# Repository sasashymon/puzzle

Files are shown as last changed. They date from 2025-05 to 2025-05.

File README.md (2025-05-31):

Práce se zaměřuje na praktické ověření principů digitálně distribuované výroby prostřednictvím návrhu a dokumentace jednoduché stoličky Puzzle. Cílem bylo vytvořit produkt, který odráží možnosti lokální digitální výroby a zároveň snižuje bariéry vstupu pro běžné uživatele díky srozumitelné dokumentaci, otevřeným výrobním datům a snadné montáži. Návrh stoličky Puzzle slouží jako případová studie propojující tech nologický potenciál s uživatelsky orientovaným designem. Práce ukazuje, že distribuovaná výroba může být díky promyšlenému návrhu a přístupnosti relevantní i pro neodbornou veřejnost.

Seznam souborů:

proUzivatele.pdf – tento průvodce výrobou 
proVyrobce.pdf – poznámky pro výrobce 
sedak[18/21].dxf, strana[18/21].dxf – kontury dílů 
puzzle[18/21].stp – 3D model 
vykres[18/21].pdf – technický výkres dílů 
puzzleParam.f3d – parametrický model pro úpravu v Autodesk Fusion

Soubory jsou připraveny pro materiál o tloušťce 18 a 21 mm. V případě použití jiné tloušťky materiálu je k dispozici parametrický model ve formátu F3D (pro Autodesk Fusion), který umožňuje snadnou úpravu.

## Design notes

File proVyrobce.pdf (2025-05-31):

## Přehled výrobních podkladů

{ proVyrobce.pdf – tyto poznámky pro výrobcC

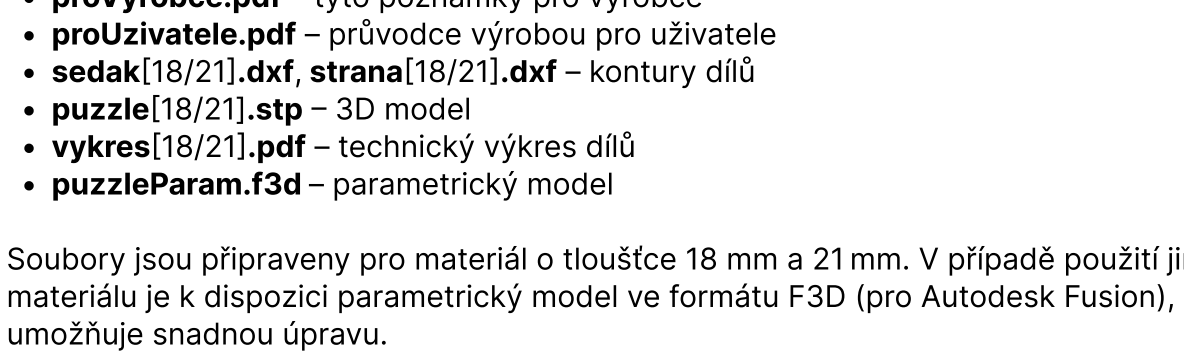
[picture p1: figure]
{ puzzle[18/21].stp – 3D mode6; { puzzleParam.f3d – parametrický model; umožňuje snadnou úpravu.

{ proUzivatele.pdf – průvodce výrobou pro uživatelC { sedak[18/21].dxf, strana[18/21].dxf – kontury díl

{ vykres[18/21].pdf – technický výkres díl

Soubory jsou připraveny pro materiál o tloušťce 18 mm a 21 mm. V případě použití jiné tloušťky materiálu je k dispozici parametrický model ve formátu F3D (pro Autodesk Fusion), který

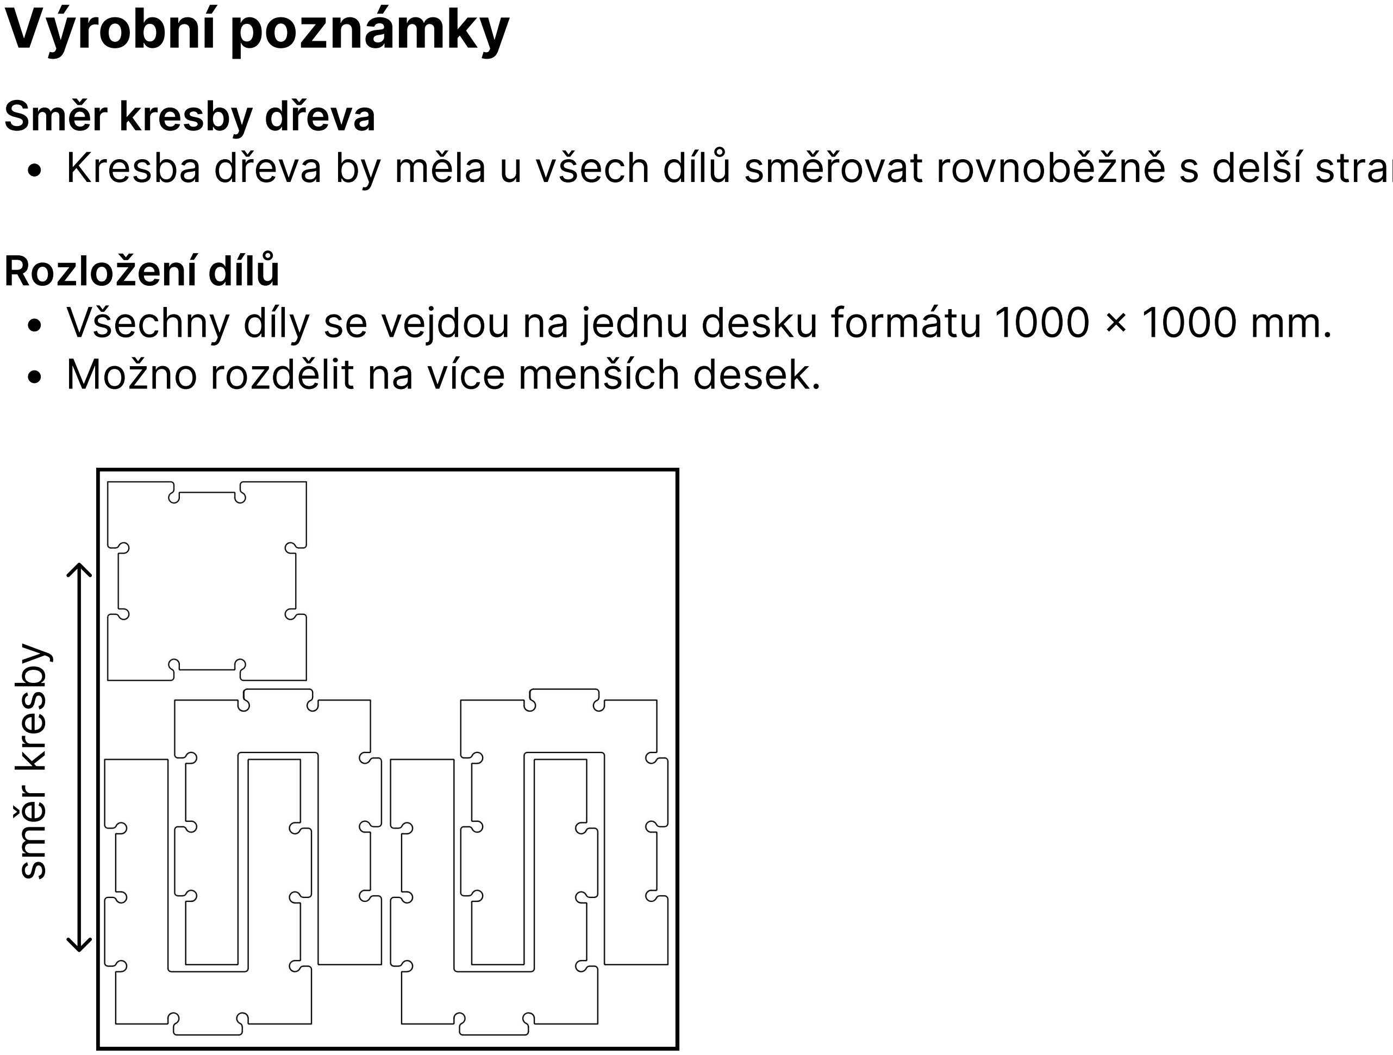
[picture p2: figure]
Výrobní poznámky; Směr kresby dřev´; Rozložení díl; ® Možno rozdělit na více menších desek.; směr kresby

® Kresba dřeva by měla u všech dílů směřovat rovnoběžně s delší stranou.

® Všechny díly se vejdou na jednu desku formátu 1000 × 1000 mm¦

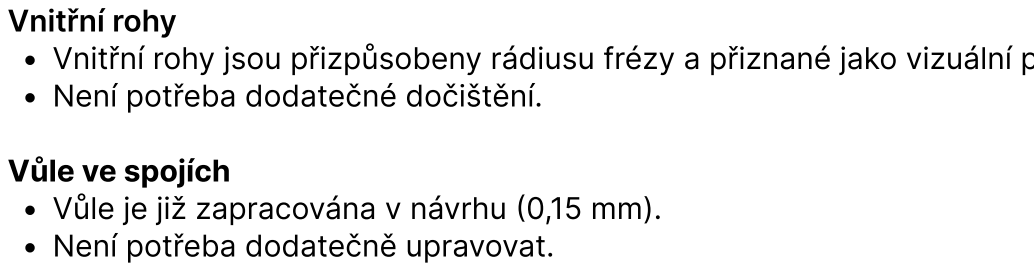
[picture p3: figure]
Vnitřní rohB; ® Není potřeba dodatečné dočištění.; Vůle ve spojíc; ® Není potřeba dodatečně upravovat.

® Vnitřní rohy jsou přizpůsobeny rádiusu frézy a přiznané jako vizuální prve

® Vůle je již zapracována v návrhu (0,15 mm)¦

1/1

# Poznámky pro výrobce stolička Puzzle

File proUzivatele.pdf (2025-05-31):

# Průvodce výrobou – stolička Puzzle

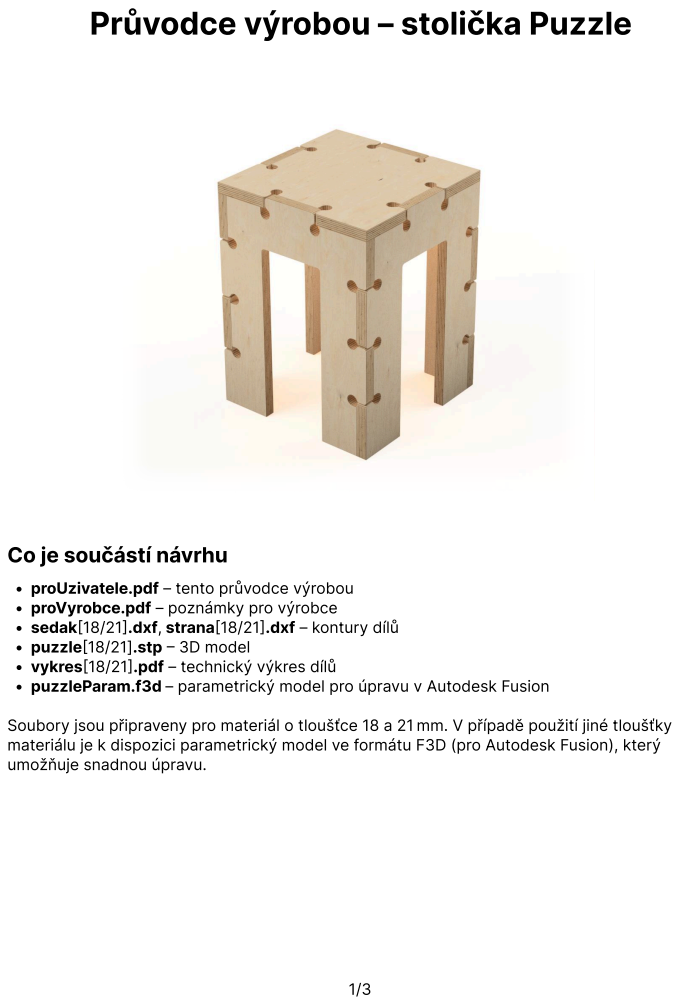
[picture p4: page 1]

Co je součástí návrhu

x proUzivatele.pdf – tento průvodce výrobo
x proVyrobce.pdf – poznámky pro výrobcW
x sedak[18/21].dxf, strana[18/21].dxf – kontury díl"
x puzzle[18/21].stp – 3D mode)
x vykres[18/21].pdf – technický výkres díl"
x puzzleParam.f3d – parametrický model pro úpravu v Autodesk Fusion

Soubory jsou připraveny pro materiál o tloušťce 18 a 21 mm. V případě použití jiné tloušťky
materiálu je k dispozici parametrický model ve formátu F3D (pro Autodesk Fusion), který
umožňuje snadnou úpravu.

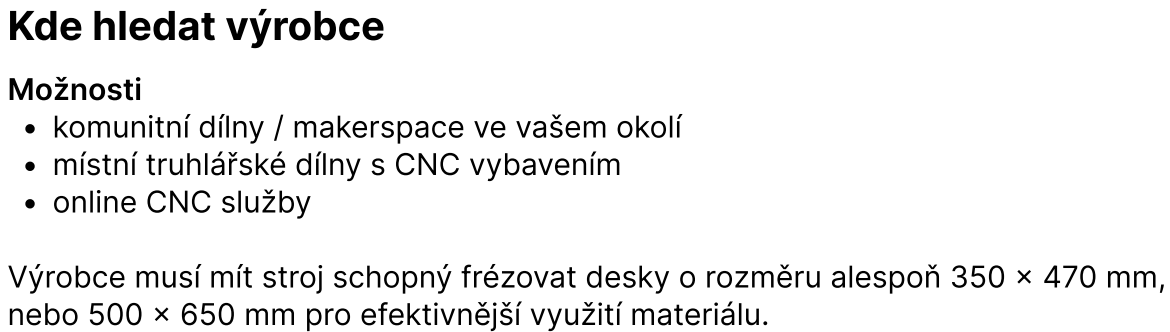
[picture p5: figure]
Kde hledat výrobce; Možnost);  online CNC služby

komunitní dílny / makerspace ve vašem okol.

místní truhlářské dílny s CNC vybavení2

Výrobce musí mít stroj schopný frézovat desky o rozměru alespoň 350 × 470 mm,

nebo 500 × 650 mm pro efektivnější využití materiálu.

## Jaký materiál zvolit

Doporučený materiál je buková nebo březová překližka tl. 18 nebo 22 mm.

Alternativně můžete použít jiný deskový materiál: např. spárovku, MDF nebo jiný druh překližky.

Tip: Pokud máte možnost, můžete využít i recyklovaný nebo zbytkový materiál.

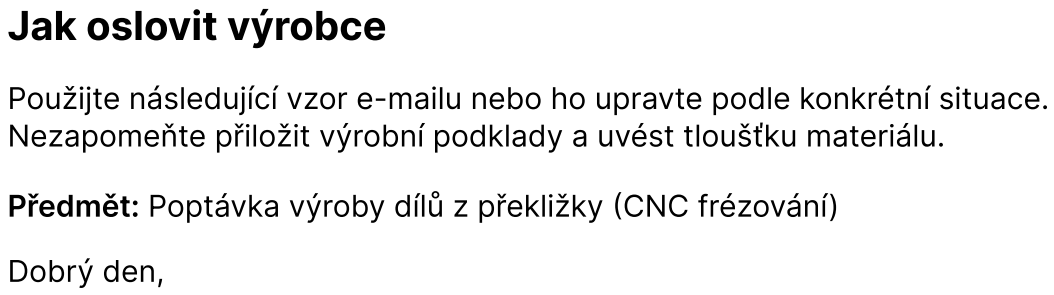
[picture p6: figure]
Dobrý den,; Jak oslovit výrobce
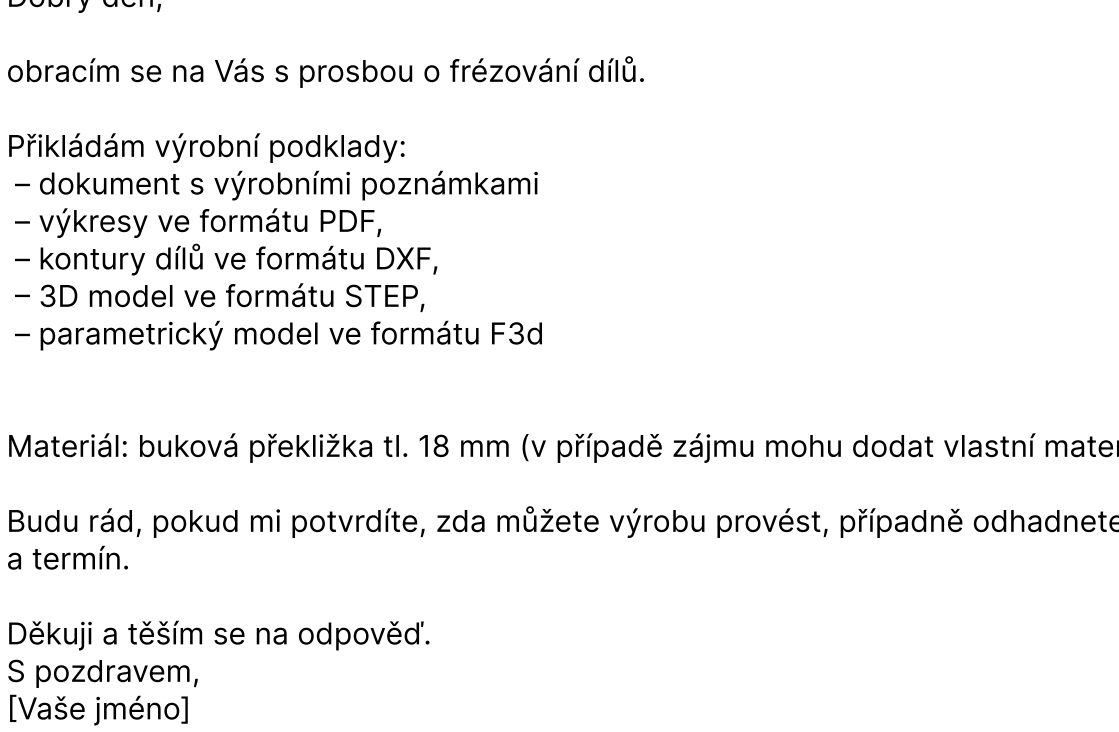
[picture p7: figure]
Přikládám výrobní podklady:; – dokument s výrobními poznámkami; – výkresy ve formátu PDF,; – kontury dílů ve formátu DXF,; – 3D model ve formátu STEP,; – parametrický model ve formátu F3d; a termín.; Děkuji a těším se na odpověď.; S pozdravem,; [Vaše jméno]

obracím se na Vás s prosbou o frézování dílů.

Materiál: buková překližka tl. 18 mm (v případě zájmu mohu dodat vlastní materiál)

Budu rád, pokud mi potvrdíte, zda můžete výrobu provést, případně odhadnete cenu

Použijte následující vzor e mailu nebo ho upravte podle konkrétní situace.

Nezapomeňte přiložit výrobní podklady a uvést tloušťku materiálu.

## Předmět: Poptávka výroby dílů z překližky (CNC frézování)

# Dokončení a sestavení stoličky

## Kontrola dílj

? Ujistěte se, že byly všechny díly vyřezány dle výkresu a nejsou poškozené.

## Jemné přebroušení a sražení hraV ? Povrch lehce přebruste jemným brusným papírem (zrnitost 180–240)` ? Ostré vnější hrany doporučuji lehce srazit (zaoblit)` ? Vnitřní detaily (např. vybrání ve spojích) lze vyčistit pomocí brusné houbičky nebo

## skládaného brusného papíru`

? Setřete prach vlhkým hadříkem.

## Povrchová úpravD ? Pro přirozený vzhled a ochranu dřeva doporučuji tvrdý voskový nebo lněný olej` ? Celková plocha všech povrchů je přibližně 1 m^2`

? Nanášejte hadříkem nebo štětcem podle návodu výrobce.

## Sestavení stoličk ? Sestavení je navržené bez použití lepidla a spojovacího materiálu` ? Začněte sedákem a postupně přidávejte boční díly podle následujících kroků:

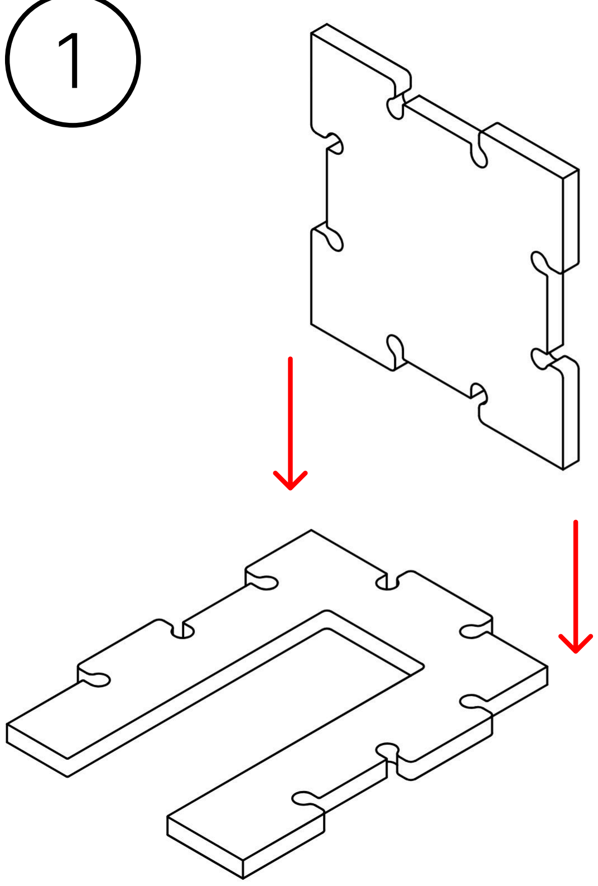
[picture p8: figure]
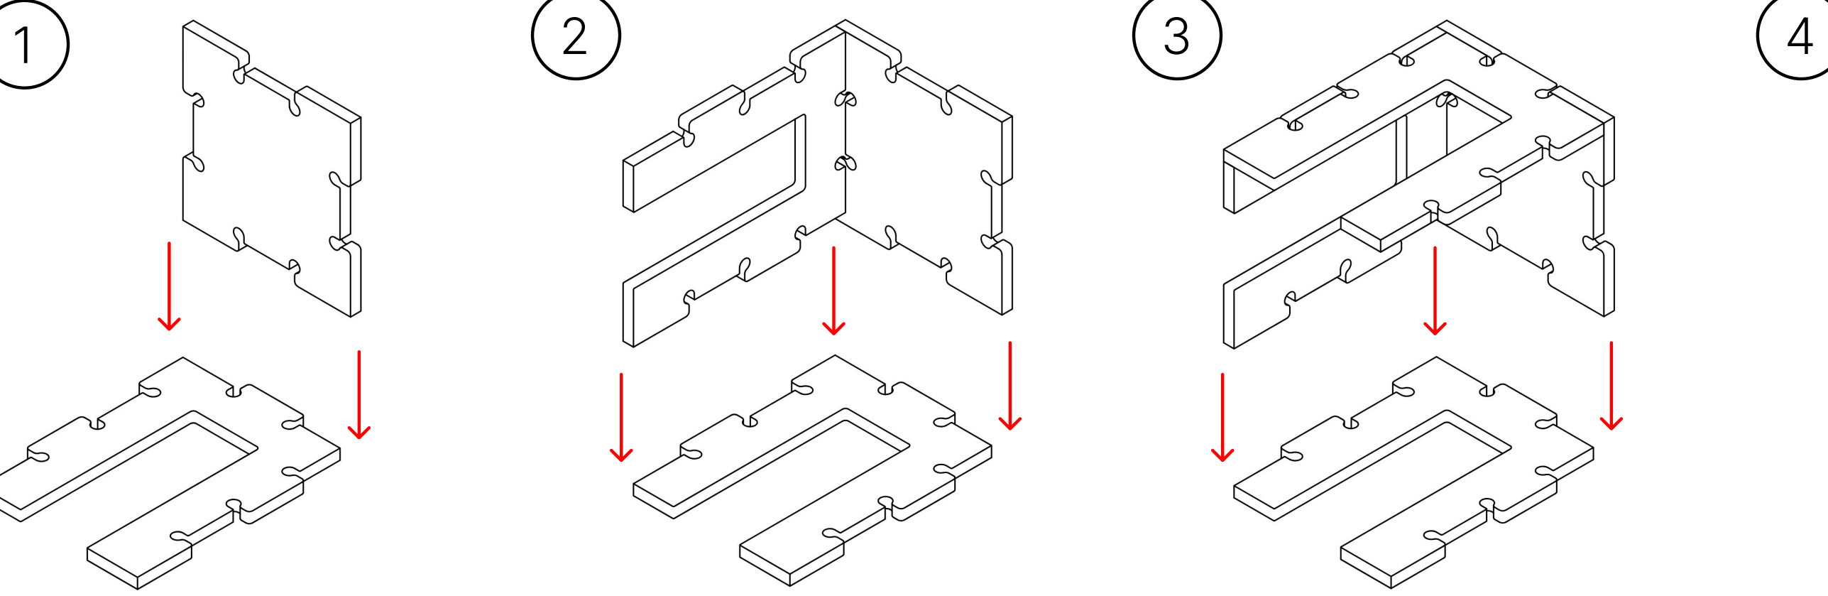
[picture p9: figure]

## ÚdržbD

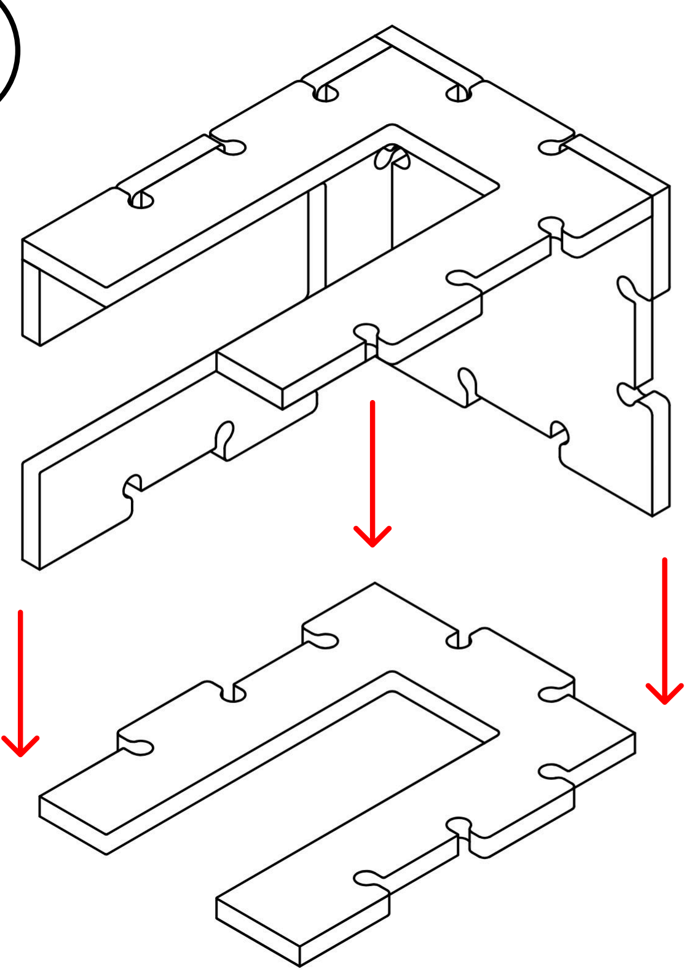
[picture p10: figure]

## ? Povrch udržujte suchý a čistý. K čištění používejte vlhký hadřík`

? Při silném opotřebení lze povrch znovu lehce přebrousit a přetřít olejem.

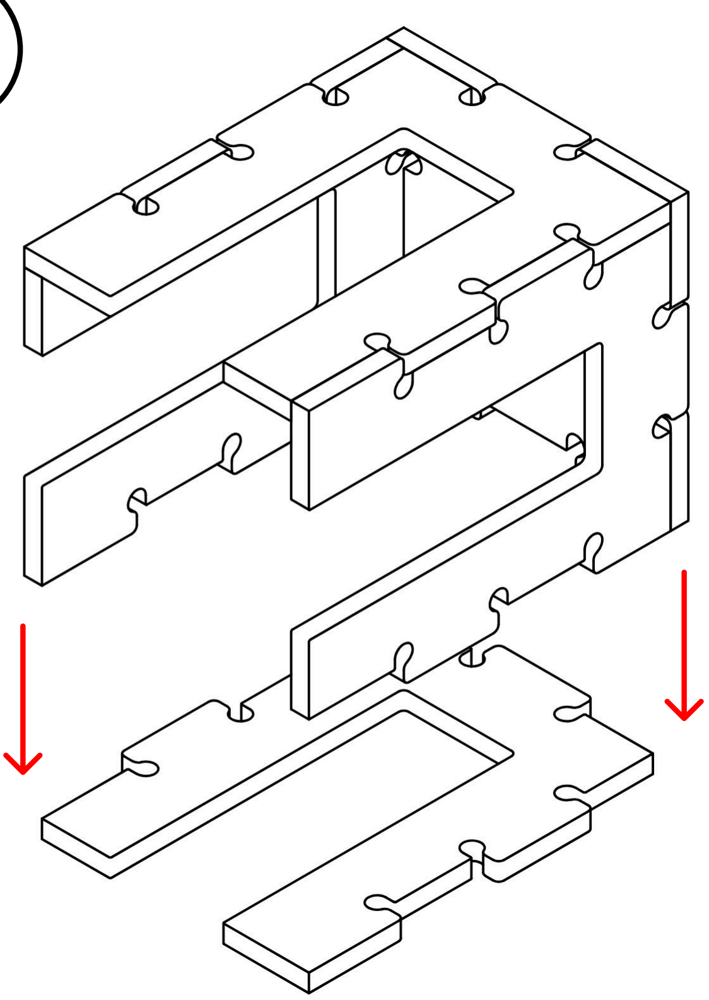
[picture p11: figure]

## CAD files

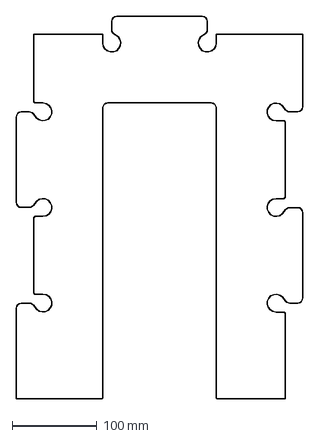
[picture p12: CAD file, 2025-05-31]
strana21.dxf
337.5 x 450.0 mm

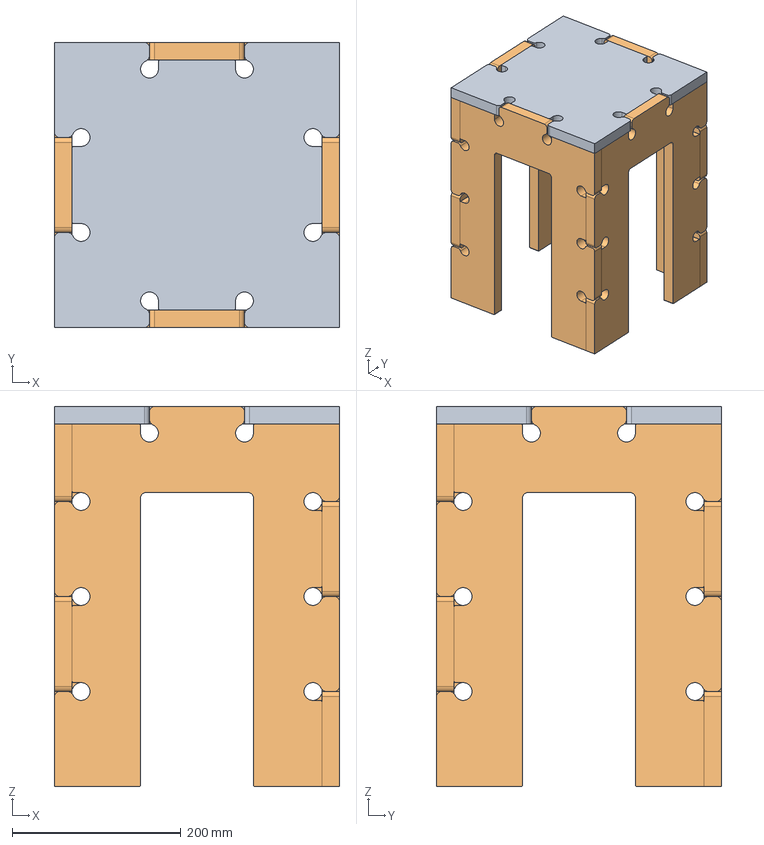
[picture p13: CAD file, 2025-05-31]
puzzle21.step
337.5 x 337.5 x 450.0 mm
seat
leg1
leg2
leg3
leg4

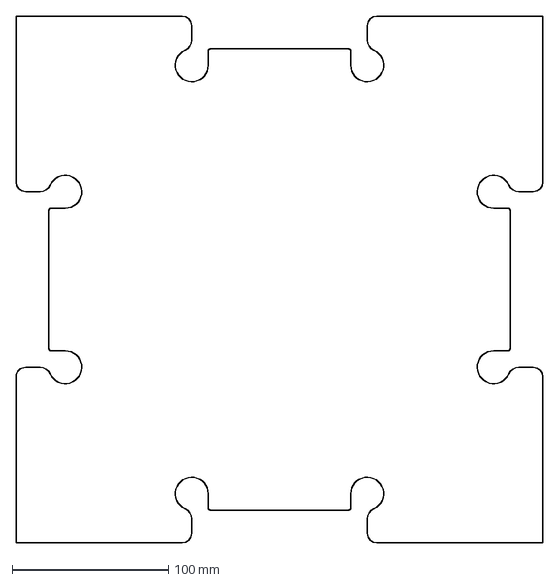
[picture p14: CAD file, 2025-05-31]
sedak21.dxf
337.5 x 337.5 mm

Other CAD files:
puzzleParam.f3d

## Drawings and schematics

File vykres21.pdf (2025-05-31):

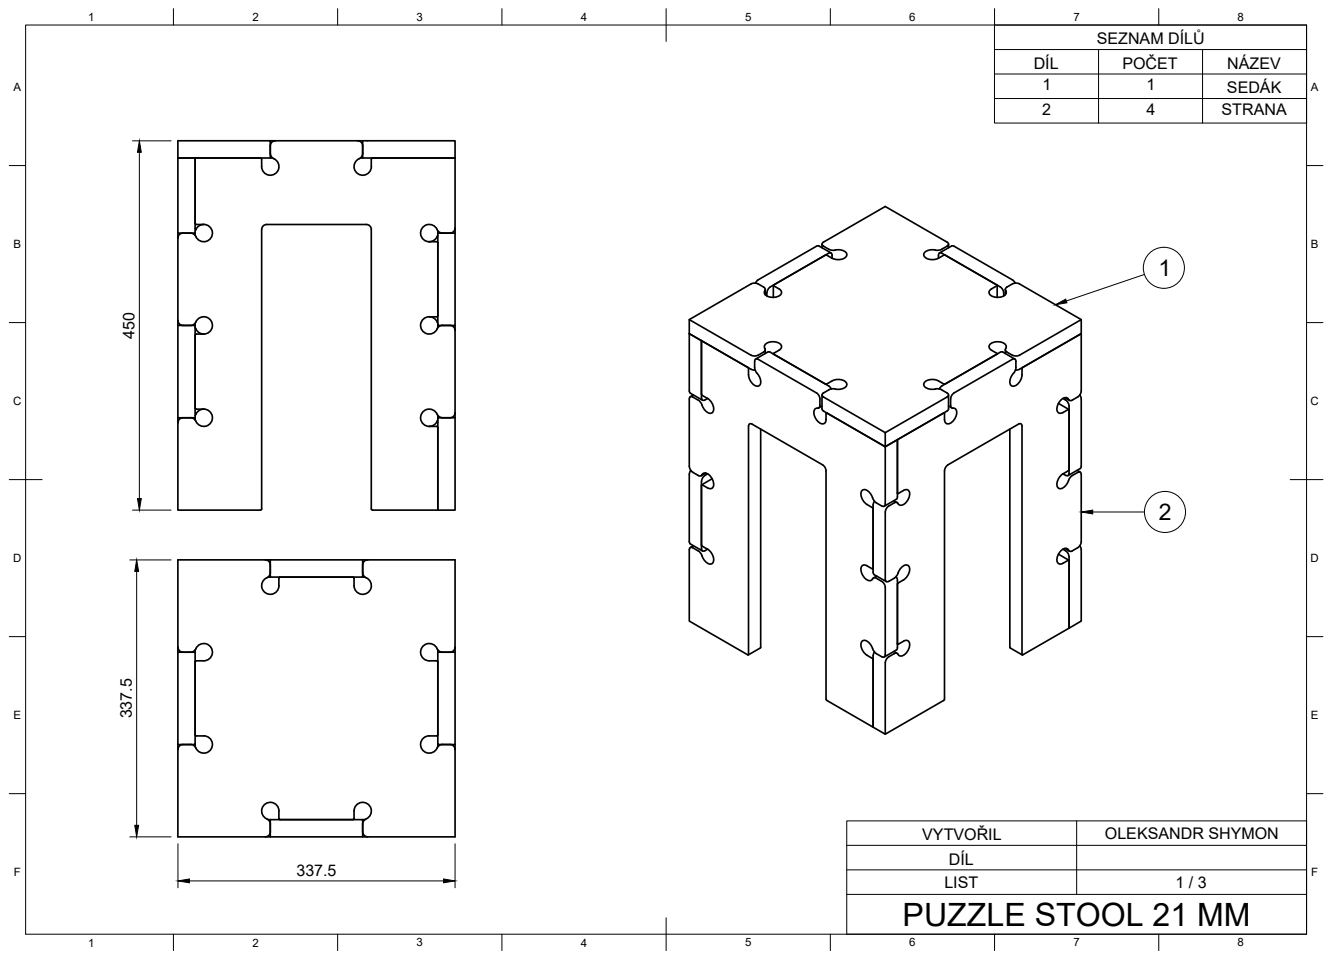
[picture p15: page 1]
SEZNAM DÍLŮ

DÍL | POČET | NÁZEV
1 | 1 | SEDÁK
2 | 4 | STRANA

VYTVOŘIL | OLEKSANDR SHYMON
DÍL
LIST | 1 / 3

PUZZLE STOOL 21 MM

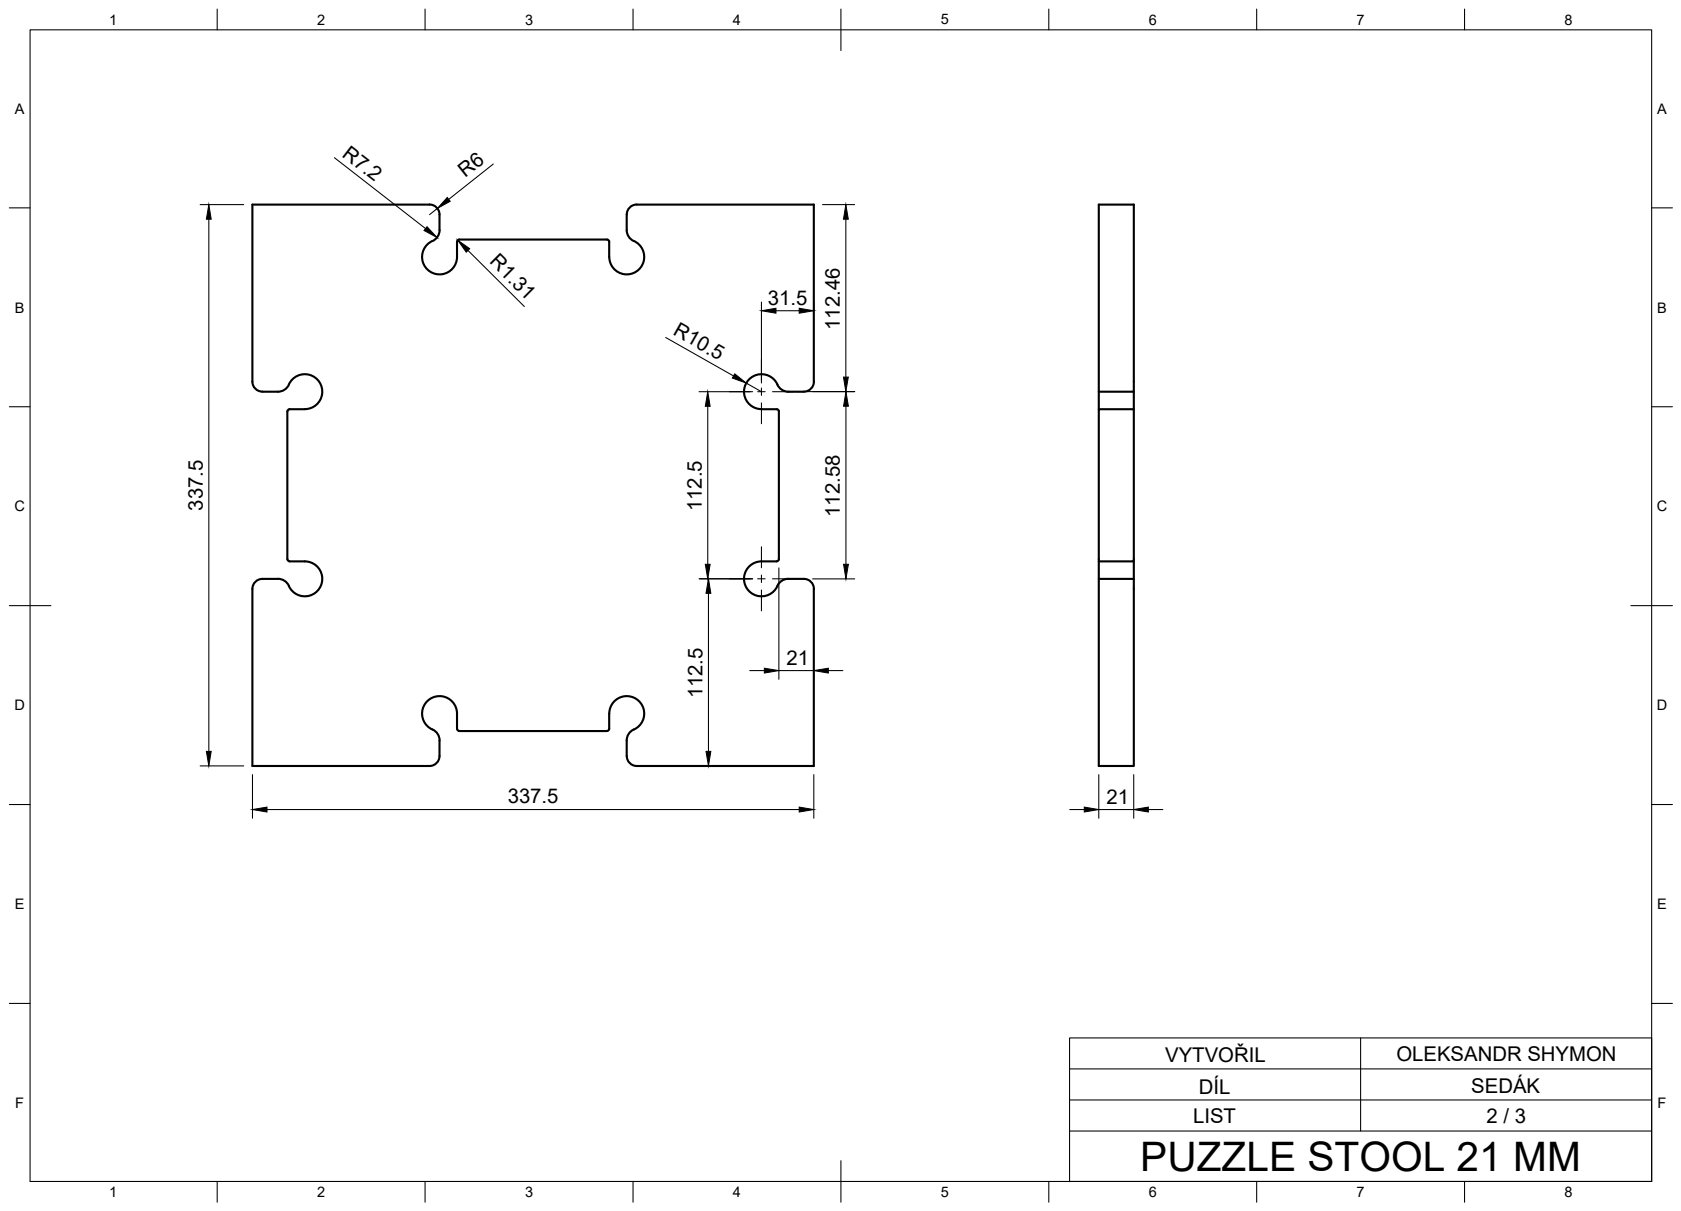
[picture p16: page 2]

VYTVOŘIL | OLEKSANDR SHYMON
DÍL | SEDÁK
LIST | 2 / 3

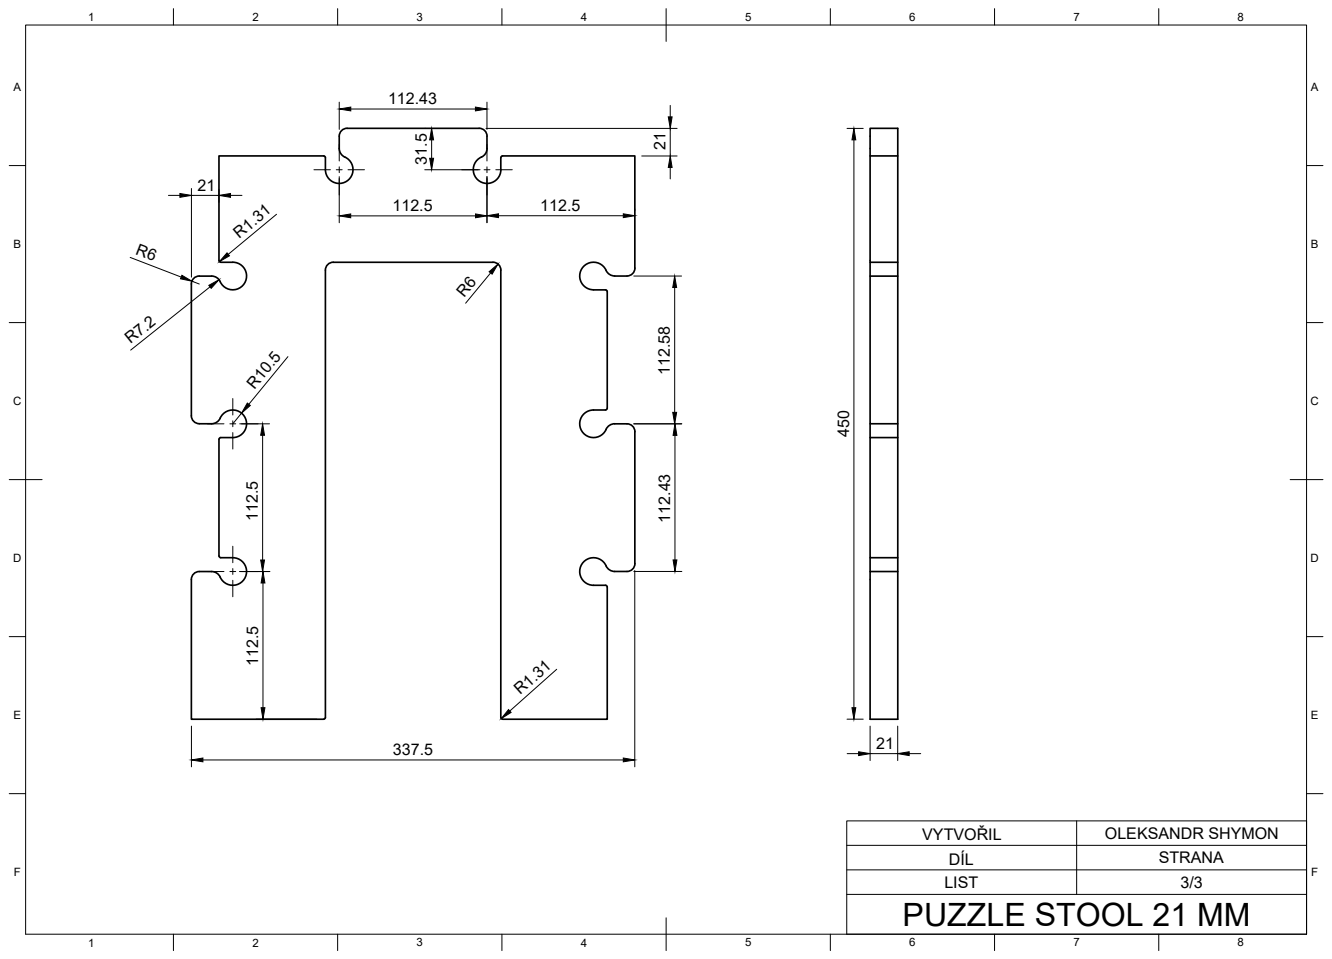
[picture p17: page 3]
8 BCDEF; ABCDEF

VYTVOŘIL | OLEKSANDR SHYMON
DÍL | STRANA
LIST | 3/3
